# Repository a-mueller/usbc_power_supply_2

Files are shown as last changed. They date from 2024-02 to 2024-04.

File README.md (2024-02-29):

# USB C POWER SUPPLY 2 (Single Cell LiPo 18650)

I made this as I couldn't find any board that did exactly what I needed. I used some of these (https://www.ebay.co.uk/itm/196094318206) before, but they have two main issues:

1) Doesn't charge with most USB chargers, as they ignore PD and only charge with USB-A to USB-C cables
2) Don't switch between battery and usb power

## Warning

This board does protect against overcharging, but not against discharge, so make sure you use protected cells.

## Schematic

[Schematic](img/schematic.png)

## PCB

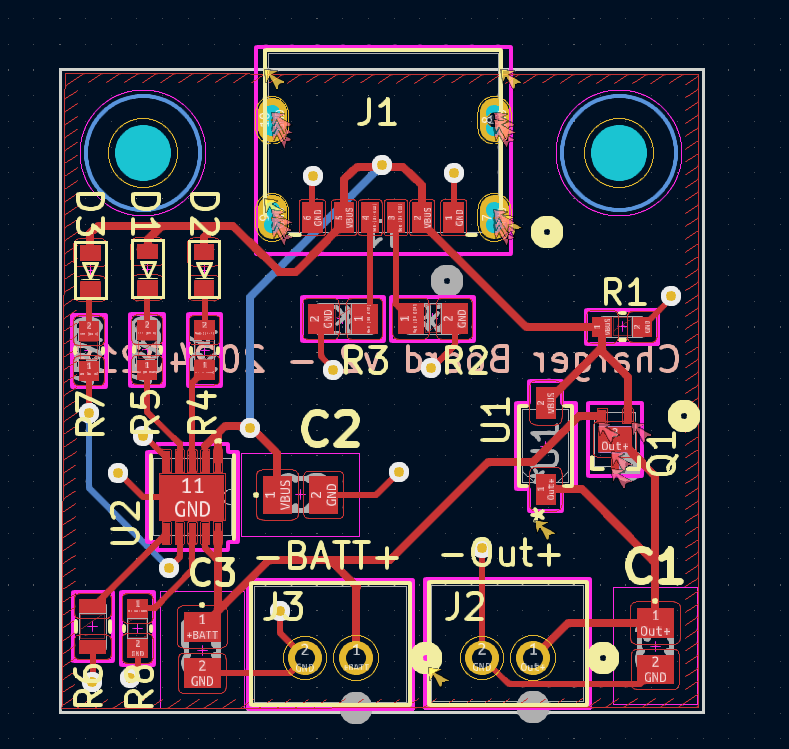
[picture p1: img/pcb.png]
PCB

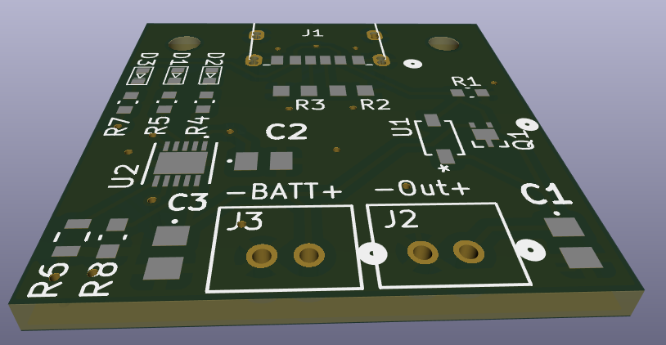
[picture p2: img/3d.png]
3DView

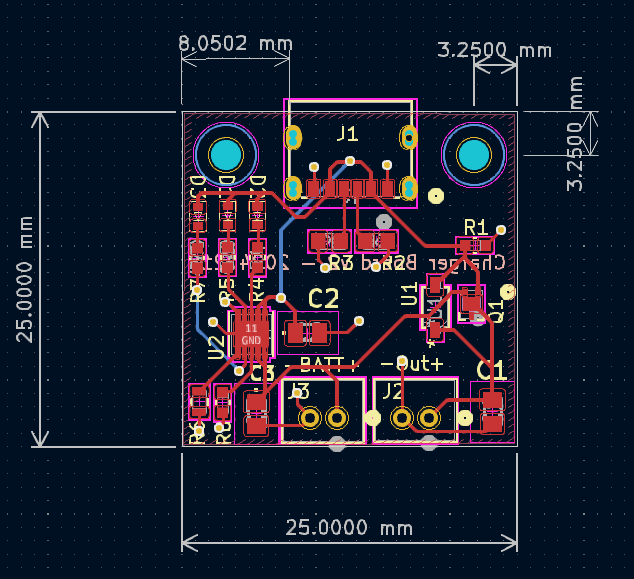
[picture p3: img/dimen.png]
Dimensions


## Parts

<table>
    <tr><td>J1</td><td><a href="https://uk.farnell.com/global-connector-technology/usb4125-gf-a-0190/usb-conn-type-c-r-a-rcpt-6pos/dp/3777661">GCT USB4125-GF-A-0190</a></td></tr>
    <tr><td>R2,R3</td><td><a href="https://uk.farnell.com/panasonic/erj6geyj512v/res-5k1-5-0-125w-0805-thick-film/dp/2057715">PANASONIC ERJ6GEYJ512V</a></td></tr>
    <tr><td>R4,R5,R7</td><td><a href="https://uk.farnell.com/panasonic/erj3geyj471v/res-470r-5-0-1w-0603-thick-film/dp/2059592">PANASONIC ERJ3GEYJ471V</a></td></tr>
    <tr><td>D1,D2,D3</td><td><a href="https://uk.farnell.com/multicomp-pro/mp008284/led-blue-200mcd-475nm-0603/dp/3796315">MULTICOMP PRO MP008284 (D1->Green, D2-> Blue, D3-> Red)</a></td></tr>
    <tr><td>R6</td><td><a href="https://uk.farnell.com/panasonic/erjup3j102v/res-1k-5-0-25w-0603/dp/3579508">PANASONIC ERJUP3J102V</a></td></tr>
    <tr><td>U2</td><td><a href="https://uk.farnell.com/microchip/mcp73833-ami-mf/batt-charger-li-ion-pol-1a-dfn/dp/2709765">MICROCHIP MCP73833-AMI/MF</a></td></tr>
    <tr><td>C1,C2,C3</td><td><a href="https://uk.farnell.com/kemet/c0805c106k8pactu/cap-10-f-10v-10-x5r-0805/dp/1463362">KEMET C0805C106K8PACTU</a></td></tr>
    <tr><td>U1</td><td><a href="https://uk.farnell.com/on-semiconductor/mbr0540t3g/diode-schottky-0-5a-40v-sod-123/dp/2101839">ONSEMI MBR0540T3G (500mA) or PMEG3010EGW (1A)</a></td></tr>
    <tr><td>Q1</td><td><a href="https://uk.farnell.com/diodes-inc/dmg3415ufy4q-7/mosfet-p-ch-16v-2-5a-x2-dfn2015/dp/3943489">DIODES INC. DMG3415UFY4Q-7</a></td></tr>
    <tr><td>R1,R8</td><td><a href="https://uk.farnell.com/panasonic/erj3geyj103v/res-10k-5-0-1w-0603-thick-film/dp/2059627">PANASONIC ERJ3GEYJ103V</a></td></tr>
    <tr><td>J2,J3</td><td>JST PH 2mm connectors</td></tr>

</table>

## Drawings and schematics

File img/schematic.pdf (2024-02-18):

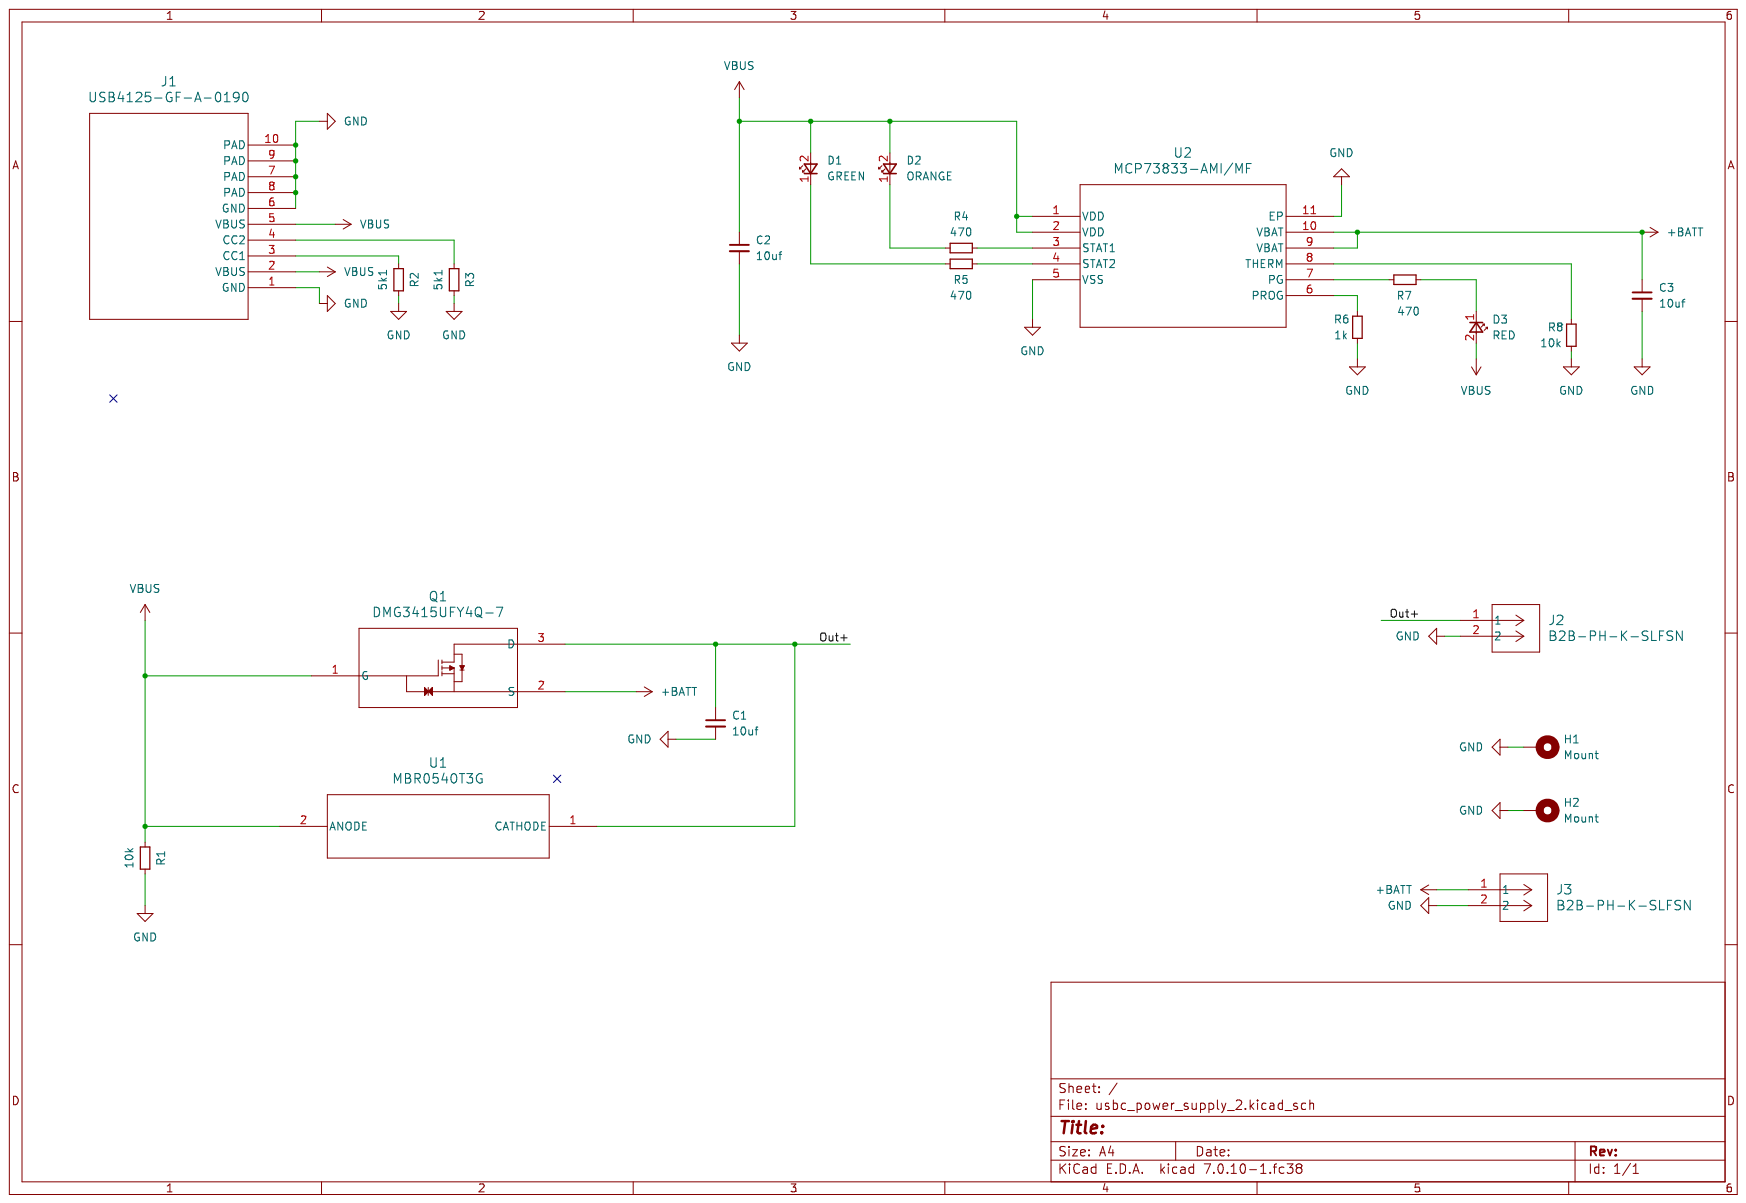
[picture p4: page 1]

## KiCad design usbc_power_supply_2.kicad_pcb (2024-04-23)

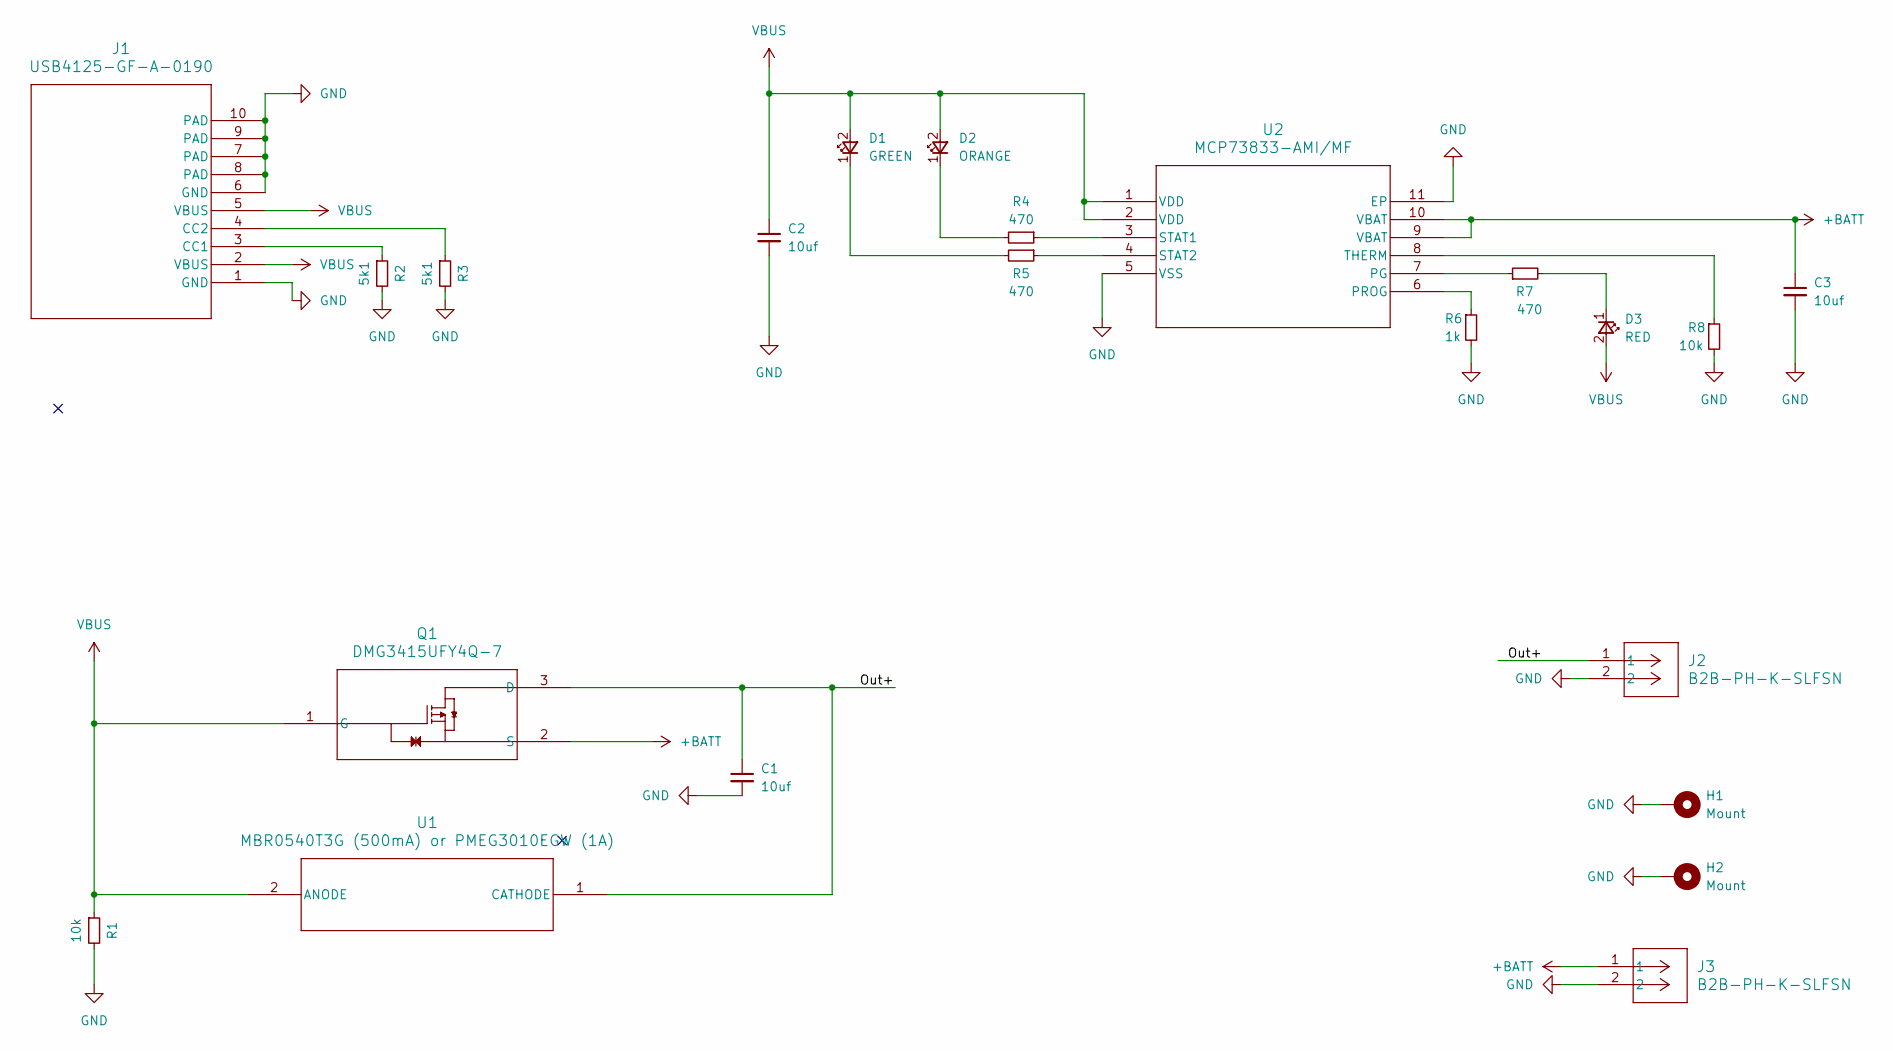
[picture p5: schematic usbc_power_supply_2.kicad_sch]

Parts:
C1, C2, C3: 10uf; C0805
D1: GREEN; Multicomp_SMD_LED_0603
D2: ORANGE; Multicomp_SMD_LED_0603
D3: RED; Multicomp_SMD_LED_0603
H1, H2: Mount; MountingHole_2.2mm_M2_Pad
J1: USB4125-GF-A-0190; CONN6_125-GF-A-0190_GCT
J2, J3: B2B-PH-K-SLFSN; CONN_B2B-PH-K-SLFSN_JST
Q1: DMG3415UFY4Q-7; TRANS_DMG3415UFY4Q-7_DIO
R1, R8: 10k; ERJ3G_PAN
R2, R3: 5k1; ERJ6G_PAN
R4, R5, R7: 470; ERJ3G_PAN
R6: 1k; ERJUP3_PAN
U1: MBR0540T3G (500mA) or PMEG3010EGW (1A); SOD-123_ONS
U2: MCP73833-AMI/MF; DFN10_3x3MC_MCH

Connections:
+BATT: C3.1, J3.1, Q1.2 (S), U2.9 (VBAT), U2.10 (VBAT)
/Out+: C1.1, J2.1, Q1.3 (D), U1.1 (CATHODE)
GND: C1.2, C2.2, C3.2, H1.1, H2.1, J1.1 (GND), J1.6 (GND), J1.7 (PAD), J1.8 (PAD), J1.9 (PAD), J1.10 (PAD), J2.2, J3.2, R1.2, R2.2, R3.2, R6.2, R8.2, U2.5 (VSS), U2.11 (EP)
unnamed: D1.1 (K), R5.2
unnamed: D2.1 (K), R4.2
unnamed: D3.1 (K), R7.2
unnamed: J1.3 (CC1), R2.1
unnamed: J1.4 (CC2), R3.1
unnamed: R7.1, U2.7 (PG)
unnamed: R6.1, U2.6 (PROG)
unnamed: R4.1, U2.3 (STAT1)
unnamed: R5.1, U2.4 (STAT2)
unnamed: R8.1, U2.8 (THERM)
VBUS: C2.1, D1.2 (A), D2.2 (A), D3.2 (A), J1.2 (VBUS), J1.5 (VBUS), Q1.1 (G), R1.1, U1.2 (ANODE), U2.1 (VDD), U2.2 (VDD)

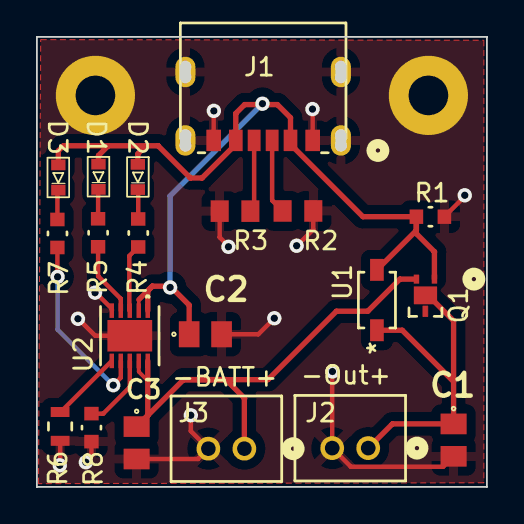
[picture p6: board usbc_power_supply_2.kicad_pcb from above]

Board: 2 copper layers, 25.0 x 25.0 mm, 22 parts (0 on the bottom side), 14 nets.

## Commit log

2024-02-18 Initial Commint
    [usbc_power_supply_2-B_Cu.gbr, usbc_power_supply_2-B_Mask.gbr, usbc_power_supply_2-B_Paste.gbr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]
2024-02-29 updates mounting holes with pads, optional 1A shottkyx
    [usbc_power_supply_2.kicad_pcb, usbc_power_supply_2.kicad_sch]
2024-04-23 upgrades board files to kicad
    [usbc_power_supply_2.kicad_pcb, usbc_power_supply_2.kicad_sch]
